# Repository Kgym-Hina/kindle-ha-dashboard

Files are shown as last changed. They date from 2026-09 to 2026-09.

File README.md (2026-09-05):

# Kindle HA Dashboard

一个面向 Kindle KT2 Basic 的 Home Assistant 电子墨水控制面板。Kindle 只负责从 Home Assistant 订阅界面 JSON、在本地渲染和处理触摸；界面编辑、数据保存和 HA 管理集中在 Home Assistant Add-on 中。设计器支持实体绑定、可搜索的房间分组实体选择器、开关/温控组件、嵌套页面、可缩放布局、对齐和图层排序。

项目参考了 [`Kgym-Hina/kindle_renderer`](https://github.com/Kgym-Hina/kindle_renderer) 的 KUAL 启动方式和 Kindle 端 Go 实现，但把图片轮播升级成了可交互的 JSON 界面协议。

## 交付内容

| 目录 | 内容 |
| --- | --- |
| `kindle/` | Kindle 端 Go 程序、KUAL 扩展文件和 ARMv7 打包脚本 |
| `ha-addon/` | Home Assistant Add-on Docker 配置和 Node 后端 |
| `web/` | React + Vite 界面编辑器 |
| `esp32/` | ESP-IDF 固件：ADC 读取磁吸底座电阻并上报 HA |
| `mechanical/` | FreeCAD 参数化外壳生成脚本和尺寸参数 |
| `schema/` | Kindle 与编辑器共用的 JSON Schema 和示例 |
| `docs/` | 架构、协议、接线和部署说明 |

已生成的交付产物：

- [Kindle ARMv7 可执行文件](kindle/dist/kindle-ha-dashboard/bin/kindle-dashboard)
- [KUAL 安装包](kindle/dist/kindle-ha-dashboard.zip)
- [FreeCAD 外壳文件](mechanical/generated/kindle-ha-dashboard-case.FCStd)

## 快速开始

### Home Assistant Add-on

1. 将本目录作为本地 Add-on 仓库，或把 `ha-addon/` 复制到 Home Assistant 的 Add-on 仓库。
2. 在 Add-on 配置中填写 `ha_url`；如果 Add-on 运行在 Home Assistant Supervisor 内，优先使用自动注入的 `SUPERVISOR_TOKEN`。
3. 安装并启动后，从 Add-on 页面打开编辑器。
4. 在编辑器中选择 `portable` 或 Home Assistant 的某个房间（Area），拖拽组件并发布。

房间列表读取 Home Assistant 的 Area Registry；这里的“房间”不是 `zone.*` 地理位置实体，也不是 HA 实例区分。

Add-on 会把文档写入以下 HA 实体，并触发标准 `state_changed` 事件：

```text
sensor.kindle_dashboard_portable
sensor.kindle_dashboard_zone_<zone_id>
```

本地预览编辑器时可在 `web/` 运行 `npm install` 后执行 `npm run dev`；生产部署推荐直接使用 `ha-addon/` 的 Docker 构建，使 React 静态文件和 backend 一起进入 Add-on 镜像。

### Kindle

复制 `kindle/config.example` 为 Kindle 扩展目录中的 `config`，填写 Home Assistant 地址、Long-Lived Access Token、设备 ID 和屏幕参数。随后在 KUAL 中启动扩展。

```text
/mnt/us/extensions/kindle-ha-dashboard/config
/mnt/us/extensions/kindle-ha-dashboard/bin/kindle-dashboard
```

ARMv7 构建和 KUAL 打包命令写在 `kindle/build_kual_package.sh` 中。根据当前工作区约束，本次不会在服务器上自动执行构建。

### ESP32

固件使用 ESP-IDF 5.x。进入 `esp32/` 后用 `idf.py menuconfig` 配置 Wi-Fi、HA URL、Long-Lived Token、ADC GPIO 和电阻区间，再烧录到贴在 Kindle 背后的 ESP32 板。

### 外壳

`mechanical/kindle_case.FCMacro` 会生成带参数的 FreeCAD 文档：Kindle 外壳腔体、底部 micro 走线孔、背面 ESP32 凹槽和 pogo pin 接口开口均由 `mechanical/parameters.json` 控制。

## 重要假设

- Kindle 逻辑显示尺寸默认 `600 × 800`，触摸坐标默认 `599 × 799`，均可在配置中修改。
- KT2 Basic、ESP32 开发板和 pogo pin 底座的实测尺寸尚未由本项目自动获得；外壳脚本采用可修改参数，不把未经测量的尺寸伪装成最终加工尺寸。
- 位置上报采用 ESP32 Wi-Fi + HA REST 状态实体；电阻区间映射由固件的 Kconfig 配置完成。
- Kindle 使用 HA WebSocket API 的 Long-Lived Access Token。界面 JSON 保存在 HA entity attributes，按钮调用使用同一条 WebSocket 连接。

## 协议入口

完整协议见 [`docs/protocol.md`](docs/protocol.md)，可校验的 Schema 在 [`schema/dashboard.schema.json`](schema/dashboard.schema.json)，可直接导入编辑器的示例在 [`schema/examples/portable.json`](schema/examples/portable.json)。

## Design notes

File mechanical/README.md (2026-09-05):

# FreeCAD 外壳

运行 `kindle_case.FCMacro` 会读取 `parameters.json` 并生成：

```text
mechanical/generated/kindle-ha-dashboard-case.FCStd
```

模型包含 Kindle 腔体、屏幕开口、底部 micro 走线孔、背面 ESP32 凹槽、pogo pin 通道和盖板安装柱。参数默认值以 Kindle 10 / 2019 基础款的公开机身尺寸为基准，KT2 Basic 实物、ESP32 板和 pogo pin 装配尺寸必须在加工前复测后再调整 `parameters.json`。

FreeCAD GUI：`菜单 → 宏 → 宏… → 运行 kindle_case.FCMacro`。

命令行生成：

```bash
/Applications/FreeCAD.app/Contents/Resources/bin/freecadcmd mechanical/kindle_case.FCMacro
```

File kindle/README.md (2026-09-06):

# Kindle 端

Kindle 端只有 Go 可执行程序，运行在 KUAL 扩展目录中。程序会：

- 使用配置文件中的 Long-Lived Access Token 连接 Home Assistant REST/WebSocket API；
- 读取 portable/zone 界面实体中的 `document` 属性并渲染灰度 PNG；
- 监听 evdev 触摸与物理键，按 JSON 的 `action` 调用 HA 服务、切换页面或弹出消息；
- 支持多级页面、底部返回/主页/设置导航，以及设置页中的刷新配置和退出程序；
- 支持文本实体绑定、开关控制和温控组件；
- 运行时停用 Kindle 原生 framework，拦截物理电源键，并持续保持屏幕唤醒；
- 订阅 `kindle_dashboard_message` 事件；
- 定时把 Kindle 电量写入 `sensor.<device_id>_battery`。

安装 `dist/kindle-ha-dashboard.zip` 后，编辑扩展根目录的 `config`，再在 KUAL 中启动。安装包内置 Noto Sans CJK SC 字体，支持中文并按 JSON 中的 `font_size` 和 `font_weight` 渲染；如需替换字体，可在 `font_path` 和 `font_bold_path` 中填写 Kindle 上的 TTF/OTF 路径。

`input_device` 默认使用 `/dev/input/event1` 触摸屏，`key_device` 默认使用 `/dev/input/event0` 物理键。物理键在子页面返回主页，在主页打开设置页面。

`dashboard_refresh_interval_seconds` 控制从 Home Assistant 定期校准界面的间隔，默认 10 秒；内容没有变化时不会刷屏。`force_refresh_interval_seconds` 控制最长刷屏间隔，默认 1800 秒（30 分钟），用于定期清除电子墨水残影。

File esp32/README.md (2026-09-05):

# ESP32 Location Bridge

这是一个 ESP-IDF 5.x 项目。ESP32 通过 ADC 读取磁吸底座的编码电阻，按 Kconfig 中的区间映射出 zone，并写入：

```text
sensor.<device_id>_location
```

## 配置与烧录

```bash
cd esp32
idf.py set-target esp32
idf.py menuconfig
idf.py build
idf.py -p /dev/cu.usbserial-XXXX flash monitor
```

在 `Kindle Location Bridge` 菜单中配置 Wi-Fi、HA 地址、Long-Lived Token、ADC GPIO、上拉电阻和 3 个区域的阻值区间。示例区间只用于开发验证，装配前必须用实测数据替换。

## 接线约定

ADC GPIO ── `R_pullup` ── 3.3V

ADC GPIO ── 底座编码电阻 ── GND

请在 ADC 输入附近增加限流和 ESD 防护。若使用的 ESP32 变体 ADC 通道与 GPIO 号不一致，需要把 `main.c` 的 GPIO 到通道映射改成该芯片的数据手册对应值。

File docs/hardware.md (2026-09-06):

# 硬件与尺寸说明

## Kindle

软件默认显示区域为 `600 × 800`，与老项目中的 `599 × 799` 原始触摸坐标保持兼容。实际机器需要用 `evtest` 确认 `/dev/input/event*` 和 ABS X/Y 最大值，再写入 Kindle `config`。默认 `input_device` 为触摸屏 `/dev/input/event1`，`key_device` 为物理键 `/dev/input/event0`；dashboard 运行时会独占物理键并禁用自动锁屏。

FreeCAD 默认按 Kindle 10 / 2019 基础款（常被称为 KT2 Basic/Kindle Basic 3）的约 `113 × 160 × 8.7 mm` 外形建立腔体；这只是公开规格基准，最终打印前仍要以手上的 KT2 实物为准。

## ESP32 电阻识别

推荐电路为：ESP32 ADC 引脚接固定上拉电阻 `R_pullup`，磁吸底座的编码电阻接到地。ADC 测得电压 `V` 后：

```text
R_unknown = R_pullup × V / (Vcc − V)
```

实际板上应增加 1% 精度电阻、TVS/ESD 保护和 ADC 输入限流。固件使用多个区间匹配：

```text
zone_id, min_ohms, max_ohms
```

建议在每个底座装配后记录 20 次测量值，再设置区间而不是直接复用示例值。

## pogo pin / micro 走线

外壳脚本默认预留：

- 底部走线槽和 micro 线出口；
- 背面 ESP32 腔体；
- 腔体与 Kindle 背部之间的 pogo pin 通道；
- 盖板螺柱和可调公差。

所有尺寸在 `mechanical/parameters.json`，单位为 mm。KT2 Basic 的精确外壳尺寸、板卡型号、连接器中心距和 pogo pin 直径必须在加工前用实物/卡尺复核。

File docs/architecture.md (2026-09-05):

# 系统架构

```text
┌────────────────────────── Home Assistant ──────────────────────────┐
│                                                                    │
│  sensor.kindle_dashboard_*  ◄── Add-on backend ◄── React editor    │
│          ▲                         │                               │
│          │ state_changed            └── REST API / event bus        │
│          │                                                         │
│  sensor.kindle_*_battery ◄──── Kindle Go ────► call_service        │
│  sensor.kindle_*_location ◄── ESP-IDF        kindle_dashboard_msg  │
└───────────────────────────┬────────────────────────────────────────┘
                            │ WebSocket + REST
                            ▼
                    Kindle e-ink device
              JSON renderer + evdev touch handler
```

## 数据流

1. React 编辑器通过 Add-on backend 读取界面文档和 Home Assistant Area Registry 房间。
2. 发布时 backend 将文档保存到 `/data/documents/`，并以 `POST /api/states/...` 写入 Home Assistant 实体属性 `document`。
3. Kindle 启动后通过 Long-Lived Access Token 连接 `/api/websocket`，订阅 `state_changed` 和 `kindle_dashboard_message`。
4. Kindle 首次启动通过 REST 获取 portable 文档；收到 location 状态后切换到对应房间文档；收到文档或绑定实体状态更新时仅在实际画面变化时重绘，并每 10 秒通过 REST 校准一次；连续 30 分钟无变化时强制刷新一次电子墨水屏。
5. 点击 JSON 中定义的 `call_service` 动作时，Kindle 直接通过 HA WebSocket `call_service` 执行服务；开关和温控组件使用同一通道执行内置服务。
6. ESP32 通过 ADC 读取底座电阻值，区间映射成房间 ID，并向 HA 写入位置实体；电阻变化才上报，避免制造事件风暴。
7. Kindle 周期性从 `/sys/class/power_supply/` 读取电量，使用 HA REST 更新电池实体。

## 模块边界

- `kindle/internal/model`：协议类型和校验，不依赖具体显示/网络实现。
- `kindle/internal/render`：纯 JSON 到灰度 PNG 的渲染，以及 Kindle 显示命令适配。
- `kindle/internal/ha`：HA WebSocket/REST 客户端、断线重连、事件解析。
- `kindle/internal/input`：Linux evdev 触摸坐标读取和事件归一化。
- `kindle/internal/power`：电池 sysfs 读取。
- `ha-addon/server`：编辑器 API、持久化和 HA 状态/事件桥接。
- `web/src`：编辑器界面，不直接保存 HA token。
- `esp32/main`：Wi-Fi、ADC、阻值映射和 HA REST 上报。
- `mechanical`：只负责参数化几何，不与电子/软件目录耦合。

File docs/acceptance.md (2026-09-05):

# 验收清单

## 软件链路

- [ ] Add-on 启动后 `/api/health` 返回 `ok: true`。
- [ ] 编辑器读取 Home Assistant Area Registry 房间，选择 portable 或房间后能加载对应文档。
- [ ] 实体字段使用带域图标的对话框，可按名称/实体 ID 搜索，并按类型和房间筛选、分组。
- [ ] 发布后 HA 中对应 `sensor.kindle_dashboard_*` 的 `attributes.document` 是完整 JSON。
- [ ] Kindle 启动日志显示 WebSocket 鉴权成功，并能在文档更新后重绘。
- [ ] Kindle 触摸按钮可以调用指定 HA 服务或切换本地页面。
- [ ] Add-on 推送的 `kindle_dashboard_message` 能在 Kindle 上弹窗，并可触摸关闭。
- [ ] Kindle 电量实体能更新到 0–100。

## 硬件链路

- [ ] 用 `evtest` 确认 Kindle 触摸设备和坐标上限。
- [ ] 用万用表/串口日志采集每个底座电阻样本，更新 ESP32 区间。
- [ ] 确认 ESP32 ADC 通道与实际 GPIO 映射，并加入 ESD/限流。
- [ ] 用实物复测 Kindle、ESP32、pogo pin 和 micro 线尺寸后更新 FreeCAD 参数。
- [ ] 打印外壳低层样件，验证屏幕不受压、底座能插拔、走线不折伤。

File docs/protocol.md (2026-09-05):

# `kindle-dashboard/v1` 协议

## 界面文档

界面 JSON 的顶层字段如下：

```json
{
  "schema": "kindle-dashboard/v1",
  "revision": 1,
  "updated_at": "2026-09-05T00:00:00Z",
  "target": {
    "mode": "portable",
    "zone_id": null,
    "width": 600,
    "height": 800,
    "background": "#ffffff"
  },
  "pages": []
}
```

当 `target.mode` 为 `zone` 时，`zone_id` 保存 Home Assistant Area 的 ID。协议字段名保留为 `zone_id`，用于兼容已有文档；编辑器中的发布目标显示为“房间”，指的是 HA Area（房间），不是 `zone.*` 地理位置实体。

每个页面包含 `id`、`name`、可选的 `parent_id`、`background` 和 `elements`。`parent_id` 用于组成可从页面跳转进入的子页。组件的公共字段为 `id`、`type`、`frame`、`style` 和可选 `action`：

- `text`：使用 `text` 显示文本。
- `button`：显示文本按钮，可触摸。
- `image_button`：图片本身就是点击区域，不额外绘制文字、填充或边框。
- `image`：显示 `image.src`，支持 HTTP(S)、本地文件和 data URL。
- `rect`：矩形/卡片。
- `line`：线段。
- `switch`：绑定开关实体，点击后调用 `switch.toggle`。
- `climate`：绑定温控实体，内置目标温度和 HVAC 模式控制。

文本和按钮可以使用 `binding` 显示实体状态或属性。编辑器会从 Home Assistant 读取实体列表和属性名，并提供“一键插入值”：

```json
{
  "text": "室温：{value} ℃",
  "binding": {"entity_id": "sensor.room_temperature", "field": "state", "decimals": 1}
}
```

编辑器画布和 Kindle 渲染器都会保留底部 72 像素作为返回、主页、设置导航栏；导航栏不属于页面元素。

## 动作

```json
{
  "type": "call_service",
  "domain": "light",
  "service": "turn_on",
  "service_data": {"entity_id": "light.living_room"}
}
```

`action.type` 可取：

- `navigate_page`：`page_id` 为本地页面 ID。
- `call_service`：`domain`、`service`、`service_data` 直接映射到 HA WebSocket `call_service`。
- `show_message`：`title`、`message` 在 Kindle 上弹出对话框。
- `refresh_config`：Kindle 内置等待页动作，重新从 Home Assistant 拉取界面配置。
- `exit`：Kindle 内置等待页动作，退出程序并恢复原生 Kindle 框架。

Kindle 每 10 秒从 Home Assistant 校准一次文档和绑定实体状态。只有实际画面发生变化时才会刷新电子墨水屏；连续 30 分钟没有变化时强制全屏刷新一次。两个间隔都可以在 Kindle `config` 中调整。

图片推荐使用编辑器上传产生的 PNG/JPEG/GIF data URL，或使用 Kindle 可访问的 PNG/JPEG/GIF HTTP(S) 地址。Kindle 只会把认证头发送给与 `ha_url` 同源的图片地址。

## Home Assistant 实体

### 界面实体

```text
sensor.kindle_dashboard_portable
sensor.kindle_dashboard_zone_<zone_id>
```

实体的 `state` 是 revision 字符串，属性中的 `document` 是完整界面 JSON。

### Kindle 位置实体

```text
sensor.kindle_<device_id>_location
```

`state` 是 Kindle 当前所在房间的 ID，属性包含 `resistance_ohms`、`raw_mv` 和 `source`。

### 电池实体

```text
sensor.kindle_<device_id>_battery
```

`state` 是 0–100 的整数，属性包含 `unit_of_measurement: "%"`、`device_class: "battery"` 和 `source`。

### 推送事件

事件类型：`kindle_dashboard_message`

```json
{
  "target_device_id": "kindle-bedroom",
  "title": "提醒",
  "message": "请关闭窗户",
  "timeout_ms": 10000
}
```

`target_device_id` 省略或为空时视为广播。

在 Home Assistant 自动化中可直接使用 `event: kindle_dashboard_message`，参考 [`docs/home-assistant-examples.yaml`](home-assistant-examples.yaml)。编辑器的“推送消息”按钮使用同一个事件接口。

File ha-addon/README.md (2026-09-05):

# Home Assistant Add-on

该目录是可被 Home Assistant Supervisor 构建的 Add-on。Docker 镜像包含两层构建：Vite 生成 React 编辑器静态文件，TypeScript backend 提供 API、Home Assistant REST bridge 和 Area Registry 房间读取，最终由同一个 Node 进程服务。

backend 通过 `/data/documents/` 保存每个 portable/房间文档，通过 HA REST API 更新 entity attributes；房间列表和实体的房间归属通过 HA WebSocket Area Registry 读取。设计器的实体字段使用可搜索、按类型和房间分组的选择器。Kindle 端只需要配置 HA 地址和 Long-Lived Access Token，不需要暴露 Add-on 端口给 Kindle。

独立 Docker 运行时可以通过环境变量设置 `PORT`、`KINDLE_DATA_DIR`、`HA_URL` 和 `HA_TOKEN`，也可以在编辑器 Settings 中配置 HA 地址和令牌。Supervisor 场景会自动读取 `SUPERVISOR_TOKEN`，默认访问 `http://supervisor/core`。

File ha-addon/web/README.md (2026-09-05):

该目录是 Home Assistant Add-on 的前端构建副本，源代码与仓库根目录 `web/` 保持一致；发布 Add-on 时 Docker 构建只读取本目录以内的文件。

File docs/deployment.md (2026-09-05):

# 部署

## Add-on 本地仓库

将仓库路径添加到 Home Assistant 的本地 Add-on 仓库，然后安装 `Kindle HA Dashboard`。Add-on 默认监听 `8099`，启用 ingress 后可从 HA 侧边栏打开。

`ha-addon/config.yaml` 中的 `options` 支持：

- `ha_url`：独立 Docker 场景下的 HA API 地址；Supervisor 场景可留空。
- `ha_token`：独立 Docker 场景使用的 Long-Lived Access Token；Supervisor 场景优先自动使用 `SUPERVISOR_TOKEN`。
- `port`：backend 监听端口。

编辑器 Settings 中的设置会写入 Add-on `/data/settings.json`，token 不会通过 GET API 返回。

Kindle 安装包内置 Noto Sans CJK SC 字体，因此中文不依赖 Kindle 的系统字体。Kindle `config` 中的 `font_path`、`font_bold_path` 分别指向安装包内的常规和粗体字体；`font_size` 使用与编辑器一致的画布像素单位。

## Kindle 发布包

在具备 Go 工具链的开发机上运行：

```bash
cd kindle
./build_kual_package.sh
```

构建产物为 `kindle/dist/kindle-ha-dashboard.zip`。此过程需要可用的 Go 编译器和 zip 工具，本仓库不提交架构相关的伪二进制。

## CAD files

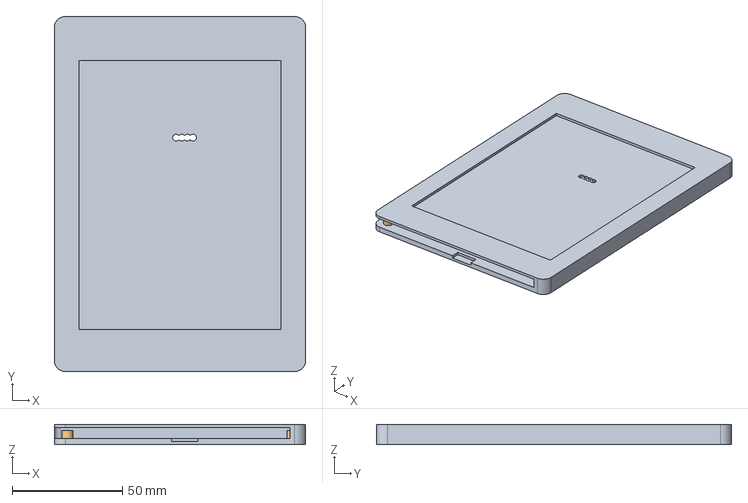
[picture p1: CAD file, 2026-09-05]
mechanical/generated/kindle-ha-dashboard-case.FCStd
113.9 x 160.9 x 9.15 mm
Kindle case shell
Cover mounting posts

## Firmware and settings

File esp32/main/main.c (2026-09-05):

#include <math.h>
#include <stdbool.h>
#include <stdio.h>
#include <string.h>

#include "esp_adc/adc_cali.h"
#include "esp_adc/adc_cali_scheme.h"
#include "esp_adc/adc_oneshot.h"
#include "esp_event.h"
#include "esp_http_client.h"
#include "esp_log.h"
#include "esp_netif.h"
#include "esp_system.h"
#include "esp_wifi.h"
#include "freertos/FreeRTOS.h"
#include "freertos/event_groups.h"
#include "freertos/task.h"
#include "nvs_flash.h"

#define TAG "kindle-location"
#define WIFI_CONNECTED_BIT BIT0

typedef struct {
    const char *id;
    int min_ohms;
    int max_ohms;
} zone_profile_t;

static const zone_profile_t zone_profiles[] = {
    {CONFIG_KD_ZONE_1_ID, CONFIG_KD_ZONE_1_MIN_OHMS, CONFIG_KD_ZONE_1_MAX_OHMS},
    {CONFIG_KD_ZONE_2_ID, CONFIG_KD_ZONE_2_MIN_OHMS, CONFIG_KD_ZONE_2_MAX_OHMS},
    {CONFIG_KD_ZONE_3_ID, CONFIG_KD_ZONE_3_MIN_OHMS, CONFIG_KD_ZONE_3_MAX_OHMS},
};

static EventGroupHandle_t wifi_event_group;
static adc_oneshot_unit_handle_t adc_handle;
static adc_cali_handle_t adc_calibration;
static bool adc_is_calibrated;

static void wifi_event_handler(void *arg, esp_event_base_t event_base, int32_t event_id, void *event_data) {
    if (event_base == WIFI_EVENT && event_id == WIFI_EVENT_STA_START) {
        esp_wifi_connect();
    } else if (event_base == WIFI_EVENT && event_id == WIFI_EVENT_STA_DISCONNECTED) {
        ESP_LOGW(TAG, "Wi-Fi disconnected; retrying");
        esp_wifi_connect();
        xEventGroupClearBits(wifi_event_group, WIFI_CONNECTED_BIT);
    } else if (event_base == IP_EVENT && event_id == IP_EVENT_STA_GOT_IP) {
        xEventGroupSetBits(wifi_event_group, WIFI_CONNECTED_BIT);
    }
}

static void wifi_init(void) {
    wifi_event_group = xEventGroupCreate();
    ESP_ERROR_CHECK(esp_netif_init());
    ESP_ERROR_CHECK(esp_event_loop_create_default());
    esp_netif_create_default_wifi_sta();
    wifi_init_config_t wifi_config = WIFI_INIT_CONFIG_DEFAULT();
    ESP_ERROR_CHECK(esp_wifi_init(&wifi_config));
    ESP_ERROR_CHECK(esp_event_handler_register(WIFI_EVENT, ESP_EVENT_ANY_ID, &wifi_event_handler, NULL));
    ESP_ERROR_CHECK(esp_event_handler_register(IP_EVENT, IP_EVENT_STA_GOT_IP, &wifi_event_handler, NULL));
    wifi_config_t station_config = {0};
    strncpy((char *)station_config.sta.ssid, CONFIG_KD_WIFI_SSID, sizeof(station_config.sta.ssid));
    strncpy((char *)station_config.sta.password, CONFIG_KD_WIFI_PASSWORD, sizeof(station_config.sta.password));
    station_config.sta.threshold.authmode = WIFI_AUTH_WPA2_PSK;
    ESP_ERROR_CHECK(esp_wifi_set_mode(WIFI_MODE_STA));
    ESP_ERROR_CHECK(esp_wifi_set_config(WIFI_IF_STA, &station_config));
    ESP_ERROR_CHECK(esp_wifi_start());
    ESP_LOGI(TAG, "Wi-Fi started");
}

static void adc_init(void) {
    adc_oneshot_unit_init_cfg_t unit_config = {
        .unit_id = ADC_UNIT_1,
        .ulp_mode = ADC_ULP_MODE_DISABLE,
    };
    ESP_ERROR_CHECK(adc_oneshot_new_unit(&unit_config, &adc_handle));
    adc_oneshot_chan_cfg_t channel_config = {
        .atten = ADC_ATTEN_DB_12,
        .bitwidth = ADC_BITWIDTH_DEFAULT,
    };
    adc_channel_t channel = (adc_channel_t)CONFIG_KD_ADC_CHANNEL;
    ESP_ERROR_CHECK(adc_oneshot_config_channel(adc_handle, channel, &channel_config));
    ESP_LOGI(TAG, "ADC GPIO=%d channel=%d", CONFIG_KD_ADC_GPIO, CONFIG_KD_ADC_CHANNEL);

#if ADC_CALI_SCHEME_CURVE_FITTING_SUPPORTED
    adc_cali_curve_fitting_config_t calibration_config = {
        .unit_id = ADC_UNIT_1,
        .atten = ADC_ATTEN_DB_12,
        .bitwidth = ADC_BITWIDTH_DEFAULT,
    };
    if (adc_cali_create_scheme_curve_fitting(&calibration_config, &adc_calibration) == ESP_OK) {
        adc_is_calibrated = true;
    }
#elif ADC_CALI_SCHEME_LINE_FITTING_SUPPORTED
    adc_cali_line_fitting_config_t calibration_config = {
        .unit_id = ADC_UNIT_1,
        .atten = ADC_ATTEN_DB_12,
        .bitwidth = ADC_BITWIDTH_DEFAULT,
    };
    if (adc_cali_create_scheme_line_fitting(&calibration_config, &adc_calibration) == ESP_OK) {
        adc_is_calibrated = true;
    }
#endif
}

static int read_adc_mv(void) {
    int raw = 0;
    adc_channel_t channel = (adc_channel_t)CONFIG_KD_ADC_CHANNEL;
    if (adc_oneshot_read(adc_handle, channel, &raw) != ESP_OK) {
        return -1;
    }
    int millivolts = 0;
    if (adc_is_calibrated && adc_cali_raw_to_voltage(adc_calibration, raw, &millivolts) == ESP_OK) {
        return millivolts;
    }
    return raw * CONFIG_KD_VCC_MV / 4095;
}

static int read_smoothed_mv(void) {
    int total = 0;
    int valid = 0;
    for (int i = 0; i < 9; i++) {
        int value = read_adc_mv();
        if (value >= 0) {
            total += value;
            valid++;
        }
        vTaskDelay(pdMS_TO_TICKS(15));
    }
    return valid == 0 ? -1 : total / valid;
}

static float resistance_from_mv(int millivolts) {
    if (millivolts <= 0 || millivolts >= CONFIG_KD_VCC_MV) {
        return INFINITY;
    }
    float voltage = (float)millivolts;
    return ((float)CONFIG_KD_PULLUP_OHMS * voltage) / ((float)CONFIG_KD_VCC_MV - voltage);
}

static const char *zone_for_resistance(float resistance) {
    for (size_t i = 0; i < sizeof(zone_profiles) / sizeof(zone_profiles[0]); i++) {
        if (resistance >= zone_profiles[i].min_ohms && resistance <= zone_profiles[i].max_ohms) {
            return zone_profiles[i].id;
        }
    }
    return "unknown";
}

static esp_err_t publish_location(const char *zone, int millivolts, float resistance) {
    char endpoint[256];
    snprintf(endpoint, sizeof(endpoint), "%s/api/states/sensor.%s_location", CONFIG_KD_HA_URL, CONFIG_KD_DEVICE_ID);
    char body[640];
    if (isfinite(resistance)) {
        snprintf(body, sizeof(body),
                 "{\"state\":\"%s\",\"attributes\":{\"friendly_name\":\"Kindle location\",\"source\":\"esp32-resistance\",\"raw_mv\":%d,\"resistance_ohms\":%.1f}}",
                 zone, millivolts, resistance);
    } else {
        snprintf(body, sizeof(body),
                 "{\"state\":\"%s\",\"attributes\":{\"friendly_name\":\"Kindle location\",\"source\":\"esp32-resistance\",\"raw_mv\":%d,\"resistance_ohms\":null}}",
                 zone, millivolts);
    }
    esp_http_client_config_t config = {.url = endpoint, .method = HTTP_METHOD_POST, .timeout_ms = 10000};
    esp_http_client_handle_t client = esp_http_client_init(&config);
    if (client == NULL) return ESP_FAIL;
    char auth_header[384];
    snprintf(auth_header, sizeof(auth_header), "Bearer %s", CONFIG_KD_HA_TOKEN);
    esp_http_client_set_header(client, "Authorization", auth_header);
    esp_http_client_set_header(client, "Content-Type", "application/json");
    esp_http_client_set_post_field(client, body, strlen(body));
    esp_err_t result = esp_http_client_perform(client);
    int status_code = result == ESP_OK ? esp_http_client_get_status_code(client) : 0;
    if (result == ESP_OK && status_code >= 200 && status_code < 300) {
        ESP_LOGI(TAG, "location=%s resistance=%.1fΩ HTTP=%d", zone, resistance, status_code);
    } else if (result == ESP_OK) {
        ESP_LOGW(TAG, "HA location update rejected: HTTP=%d", status_code);
        result = ESP_FAIL;
    } else {
        ESP_LOGW(TAG, "HA location update failed: %s", esp_err_to_name(result));
    }
    esp_http_client_cleanup(client);
    return result;
}

void app_main(void) {
    esp_err_t nvs_result = nvs_flash_init();
    if (nvs_result == ESP_ERR_NVS_NO_FREE_PAGES || nvs_result == ESP_ERR_NVS_NEW_VERSION_FOUND) {
        ESP_ERROR_CHECK(nvs_flash_erase());
        nvs_result = nvs_flash_init();
    }
    ESP_ERROR_CHECK(nvs_result);
    wifi_init();
    adc_init();
    xEventGroupWaitBits(wifi_event_group, WIFI_CONNECTED_BIT, pdFALSE, pdFALSE, portMAX_DELAY);
    const char *last_zone = "";
    TickType_t last_report = 0;
    while (true) {
        int millivolts = read_smoothed_mv();
        float resistance = millivolts < 0 ? INFINITY : resistance_from_mv(millivolts);
        const char *zone = millivolts < 0 ? "unknown" : zone_for_resistance(resistance);
        TickType_t now = xTaskGetTickCount();
        bool interval_elapsed = now - last_report >= pdMS_TO_TICKS(CONFIG_KD_REPORT_INTERVAL_SEC * 1000);
        bool zone_changed = strcmp(last_zone, zone) != 0;
        bool retry_window_open = last_report == 0 || now - last_report >= pdMS_TO_TICKS(5000);
        if ((zone_changed && retry_window_open) || interval_elapsed) {
            if (publish_location(zone, millivolts < 0 ? 0 : millivolts, resistance) == ESP_OK) {
                last_zone = zone;
            }
            last_report = now;
        }
        vTaskDelay(pdMS_TO_TICKS(1000));
    }
}

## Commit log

2026-09-05 feat: add Kindle Home Assistant dashboard stack
    [kindle-ha-dashboard-case.FCStd]
2026-09-05 fix: filter climate and switch entity bindings
2026-09-05 fix: resolve entity areas through devices
2026-09-05 fix: keep Kindle framework stopped and restore switch controls
